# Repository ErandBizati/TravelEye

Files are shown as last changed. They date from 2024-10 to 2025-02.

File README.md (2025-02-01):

# TravelEye
<p align="center">
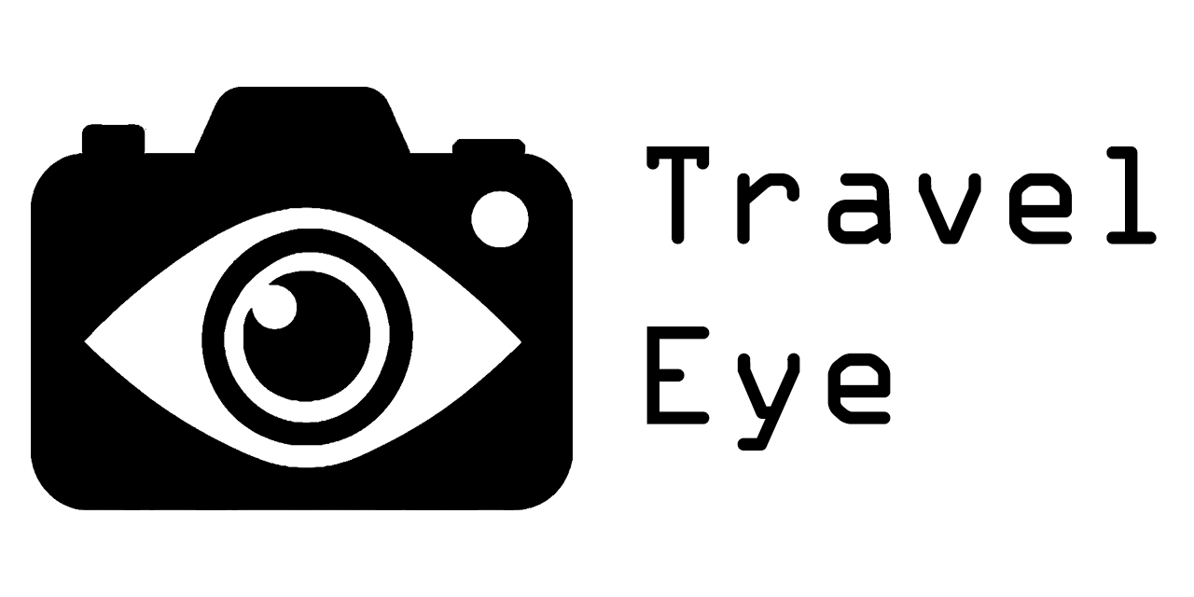
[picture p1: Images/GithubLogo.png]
  
</p>

<p align="center">
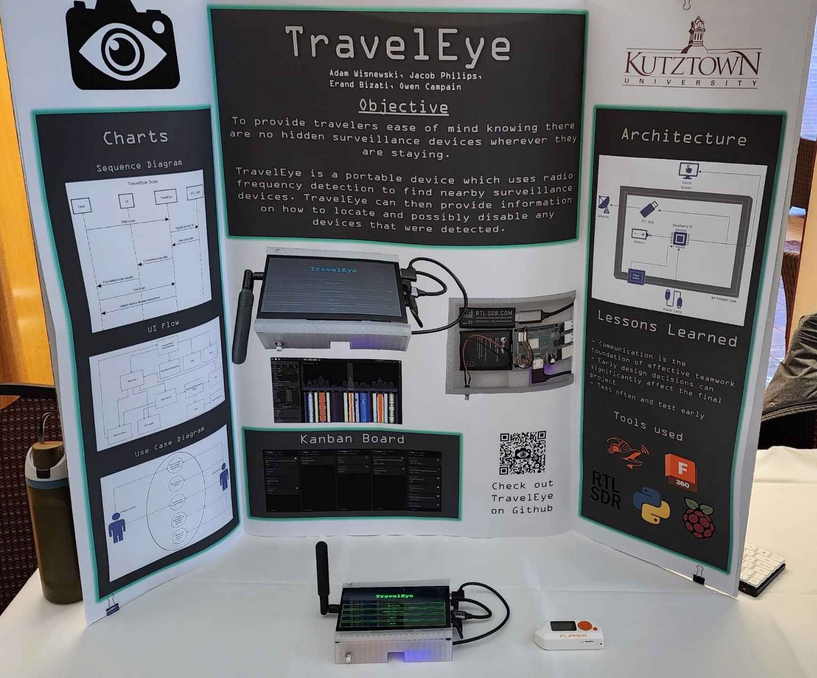
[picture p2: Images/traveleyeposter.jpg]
TravelEye Poster
  
</p>

## About
TravelEye is a portable device which used radio frequency detection to find hidden surveillance devices.
This device is aimed towards travelers with any level of technical knowledge

TravelEye scans using a list that contains frequencies that are known to be associated with surveillance devices. Any frequencies that are found to be above a determined threshold are shown to the user as possible surveillance devices.
The user can then select one of the found signals and TravelEye will then perform a focused scan on just that frequency. It will continuously scan, updating the signal strength so the user can walk around and watch the strength of the signal change for different parts of a room.
The user can then go through a few questions and TravelEye can provide advice on how to locate and possibly disable the device.

*Created by Owen Campain, Adam Wisnewski, Jacob Philips, Erand Bizati*

This project was created for a capstone course (CSC355) at Kutztown University and was formally presented at Kutztown's Demo Day 2024

## Installation
### Materials
This device was made with one specific list of components; however, this project could be recreated with slightly different components and still function. Below are the generic components required for the project along with exact models used by the team in parenthesis.
- RTL-SDR (V3)
- Raspberry Pi (3B+)
- Raspberry Pi Battery (PiSugar S Plus)
- Touch Screen (Hosyond 7-inch HDMI)
- SMA Antenna (Bingfu BFN00419)
- Normal Open Button (Twidec Push Button 7mm) 

This project uses a custom 3D printed case. The STL file for printing can be found in the repository `TravelEyeCase.stl`. Black PLA filament was used for the final case. Case design is based on the exact parts used therefore, if any components are swapped out, the case might no longer fit all components

### Assembly
The following diagram shows the layout of all the device components within the case

<p align="center">
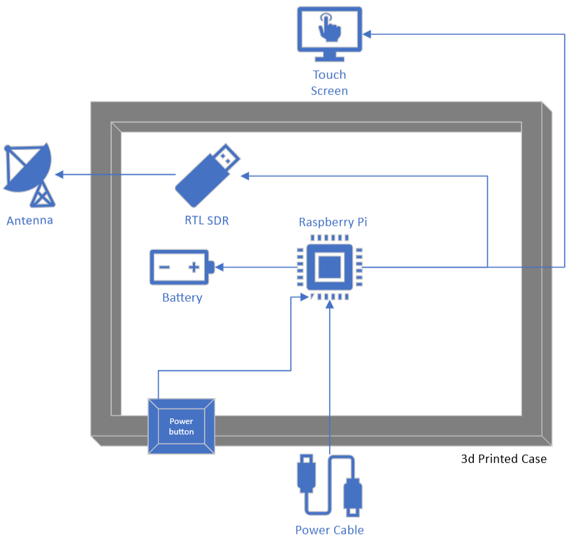
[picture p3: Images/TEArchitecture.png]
  
</p>

The screen is connected to the Raspberry Pi via HDMI. The screen is also powered by the Raspberry Pi by connecting a USB type A port of the Raspberry Pi to one of the micro-USB ports on the screen

The RTL SDR is connected to the Raspberry Pi via USB Type A. USB Type A male to female cable was used in order for the RTL-SDR to fit inside of the case, however the RTL-SDR could be connected directly.

The antenna is attached to the RTL-SDR using the SMA connector.

The power button uses the number 5 and 6 pin on the Raspberry Pi

### Software Requirements
The TravelEye program runs off the Raspberry Pi which should be running Raspbian OS. Before being able to run program though, there are a few dependencies that need to be installed first

- [RTL SDR Drivers](https://www.rtl-sdr.com/rtl-sdr-quick-start-guide/)
- [PyQt5](https://pypi.org/project/PyQt5/)
- [pi-power-button](https://github.com/Howchoo/pi-power-button.git)

### Running TravelEye
One the device has been assembled and all software requirements have been installed, TravelEye is ready to run

First make sure that `TravelEye.py`, `multipleChoiceMenu.py`, `MultiSigDetection.py` are located in the same folder before running

You can then start the program by running `TravelEye.py`

## Making Scan Adjustments
Scanning for such a wide range of different frequencies can be a challenge

There are many small adjustments to how this device scans which can affect what devices are found

There are two things that can be easily changed which can affect how the device works in different scenarios. You can adjust these values to make the device better suit your environment

### **Search list**

  This is the list of all frequencies which TravelEye will scan for.
  This list is contained in `dangerousFrequencies.txt`.

  You can add or remove any frequencies on this list. Keep in mind that all values are in MHz. The effective frequency range this device can scan for is 24 – 1766 MHz
 
  *Caution: The length of the list affects the length of scans. Adding too many frequencies can slow down the scan time*.

### Threshold
  This value represents the strength of the signal for it to be considered found. TravelEye collects data for all signals that were on the search list, however it only shows signals that we found to be above the threshold. 
  This value can be changed to make TravelEye more or less sensitive for finding signals 

  This value is contained in `MultiSigDetection.py` using the `THRESHOLD` variable. The threshold is measured in decibels

  *Caution: The UI and threshold was adjusted to only show the most prominent signals in order to not overwhelm the user with too many signals which might not be relevant. Making the threshold too low may cause all signals to be displayed which could break the UI* 

## User Guide
Here are some basic instructions and information on using TravelEye

### Instructions:

**1. Tap Start to scan**

  Scans once for all device ranges
  
  Signal strength is measured in decibels
  
  The higher the value, the stronger the signal
  
**2. Tap a found frequency to begin a focused scan**

  The device will repeatedly scan for one signal
  
  Watch the signal strength change as you move around
  
  Use this to locate where the signal is strongest
  
**3. Tap next to answer some questions to help locate the device**

### FAQ

_How close to a device do you need to detect it?_

There is no exact range on how far TravelEye can detect, it mainly depends on the strength of the signal it is trying to detect.
Most hidden devices put out a strong enough signal that TravelEye can detect as long as you are in the same room.
There have been some cases where TravelEye can detect from another room, but that is not always consistent.

_Can TravelEye find any camera or microphone?_

No, Currently TravelEye is intended to find cameras and microphones made for surveillance purposes which use radio frequency to communicate. 
Cameras and microphones which use wired or Wi-Fi communication cannot be found.
Our team would love to expand TravelEye's capabilities in the future, but for now TravelEye focuses on a more niche group of devices.

_What should I do if I find a device and cannot disable it?_

It is recommended to research surveillance and recording laws for your state/country as well as contacting the manager of the location you are staying. 
Every situation is different, so it is important to find out your rights. In many places, the authorities can be contacted if your right to privacy is being violated.

### Demo
Here is quick demo of the TravelEye device
https://www.youtube.com/watch?v=QhOCgh7br6o

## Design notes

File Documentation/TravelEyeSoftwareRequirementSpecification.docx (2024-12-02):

Software Requirement Specification

TravelEye

Dec 2, 2024

Version 2

Logo

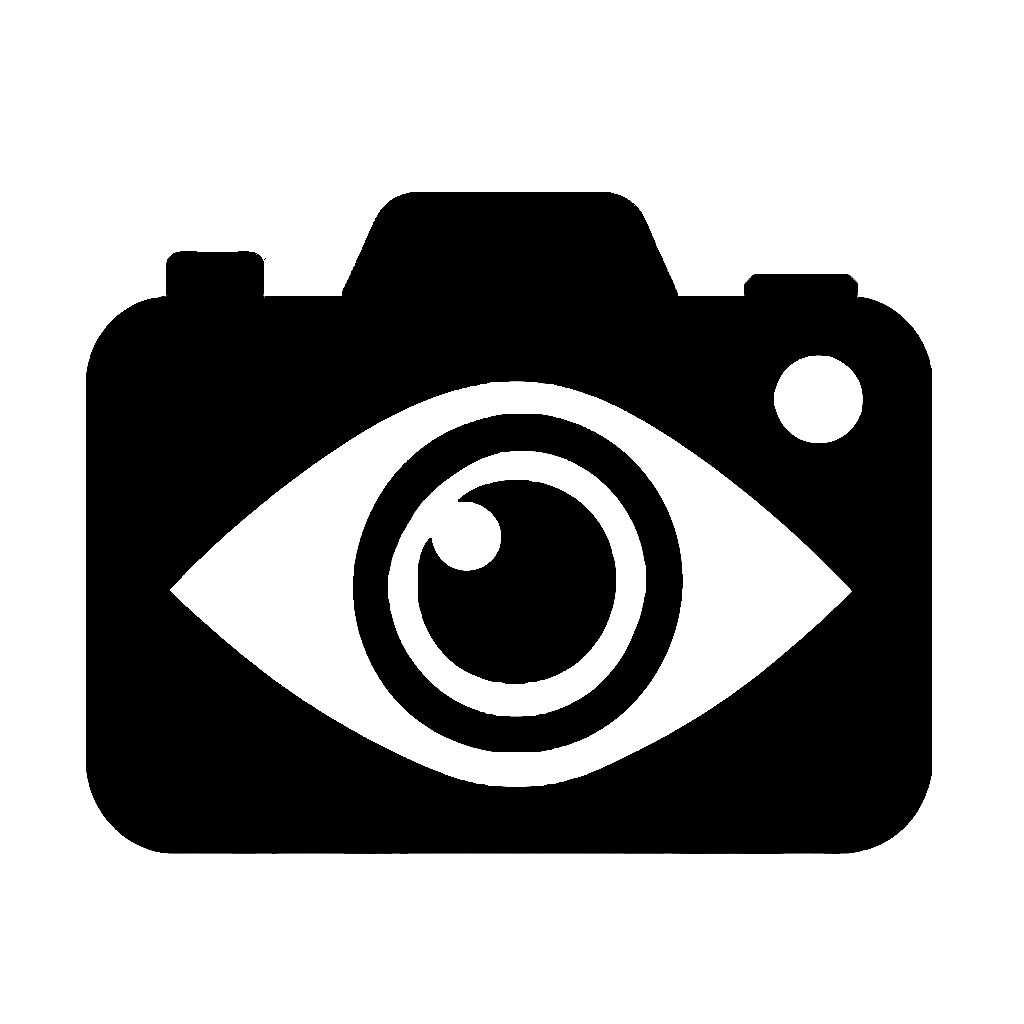
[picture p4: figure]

Presented To:

CSC354

Submitted By:

Erand Bizati

Owen Campain

Jacob Philips

Adam Wisnewski

Table of Contents

Revision History 1

1.0 Introduction 2

1.2 Scope 2

2.0 Related Documents 3

3.0 Requirements 3

3.0.1 Punch List 4

3.1 Traveler Use Cases 4

3.1.1 Disable Device Instructions 4

3.1.2 View Detected Signals 5

3.1.3 Detect Wireless Signals 5

3.1.4 Charge & Power On Device 6

3.1.5 View Help Page 6

3.1.6 User Interface Requirements 7

4.0 Non Functional Requirements 8

4.1 Other Systems 8

4.2 Usability 8

4.3 Performance 8

4.4 Maintainability 8

5.0 Architecture 9

Signature Page 9

### Revision History

Date | Author | Distributed to | Version | Description
Mar 26, 2017 | DeMarco | class | 0 | template
Feb 6, 2024 | Team | | 1 | Document creation
Dec 2, 2024 | Adam, Owen | | 2 | Revise based on final project

# 1.0 Introduction

This project aims to create a device that can help detect hidden surveillance items for travelers staying in temporary lodging (hotels, Airbnb, resorts, ect.). This device should be easy to use and accessible to all levels of technical knowledge. The device will use radio frequency detection to identify any possible hidden surveillance devices (cameras, audio recorders, gps trackers). If a potential device were to be found, instructions on how to find and disable the device will be given to the traveler.

This document outlines the different specifications and requirements for this device in order to reach the project's goal.

# 1.2 Scope

The following context diagram defines the actors that are outside the system:

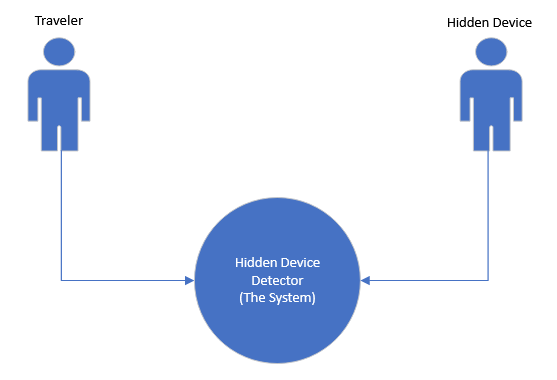
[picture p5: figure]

Traveler:

The traveler is a term used for the person using the hidden device detector.

Hidden Device:

The hidden device is any type of surveillance device which is hidden from the traveler and gives off a radio frequency which the hidden detector could capture.

The following use case diagram outline all of the possible interactions of outside actors with the system:

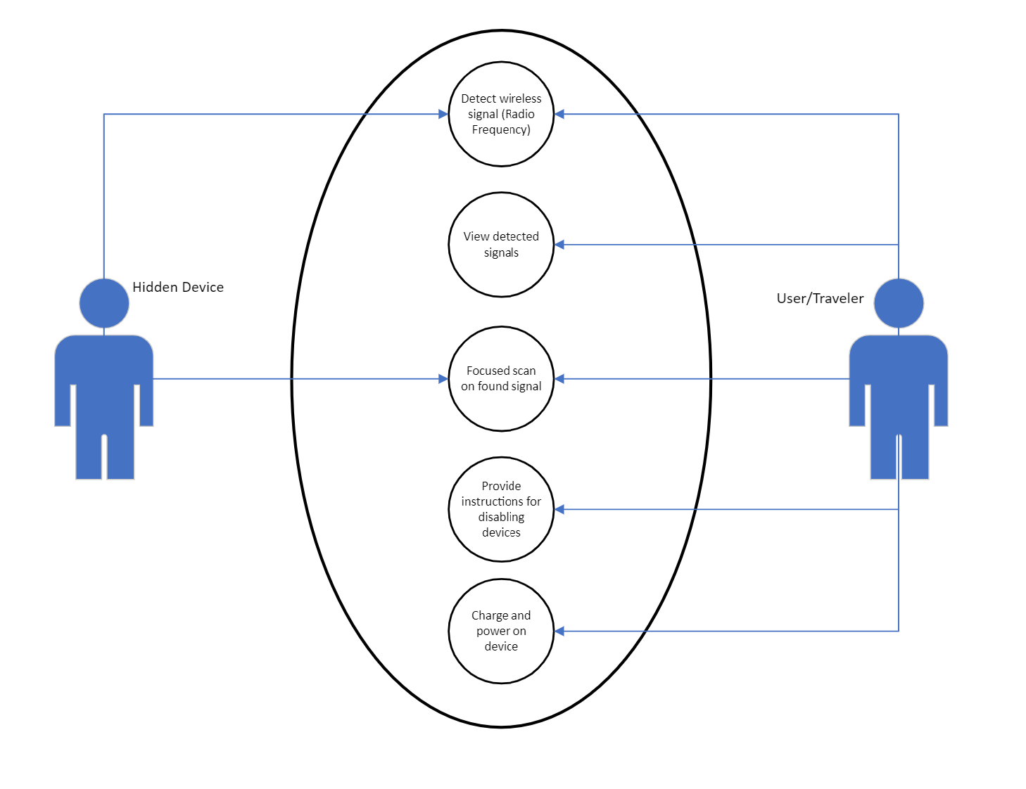
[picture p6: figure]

# 2.0 Related Documents

Context diagram link (https://livekutztown-my.sharepoint.com/:u:/g/personal/ocamp731_live_kutztown_edu/EfgFj-SR3vRDpL-uXIwYaXIBtWyubmAtK4f2kyQ_DjDRew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)

User stories link (https://livekutztown-my.sharepoint.com/:w:/g/personal/ocamp731_live_kutztown_edu/EWKVq6K5wFBMgKUtSu_duCwBPiiVJmcgEb2n8JfCiHcrRQ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)

Use case diagram link (https://livekutztown-my.sharepoint.com/:u:/g/personal/ocamp731_live_kutztown_edu/EYCpy4jRvH9Dqu8j2hU3GG8BV4mq3jjaOgJnNMZ3DxsZhQ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)

Use case description link (https://livekutztown-my.sharepoint.com/:w:/g/personal/ocamp731_live_kutztown_edu/Ef0b5joFGqxItQ4MdqtdzXMBfyyNTd9R-CmtZxJ7pXRLpg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)

# 3.0 Requirements

For each Actor, list all the user stories:

As a Traveler I want to…..

- Turn on the device
- Charge device
- Scan for signals using device
- See any signals detected
- Learn steps to disable device
- Find out how to hinder device if unable to disable

As a Hidden device I want to…..

- Emit a radio frequency for the device to read

## 3.0.1 Punch List

The following list are the items still to be resolved:

1. Figure out how to get signal information from SDR++ to our own software
2. Design the hardware architecture
3. Figure out language and platform for our software
4. Design UI flow
5. Order needed hardware

# 3.1 Traveler Use Cases

## 3.1.1 Disable Device Instructions

Description: Be informed on how to disable a hidden device when found

1. Participating Actor(s):
  a. Traveler
  b. Hidden Device
2. Entry: Hidden Device is found
3. Exit: Device is disabled
4. Flow of events:
  a. Device signal is detected
  b. User receives instructions on how to find the device
  c. User finds device
  d. User receives instructions on how to identify the type of device
  e. Hidden device type is determined
  f. User receives instructions on how to disable that type of device
  g. User disables device
5. Special Requirements:
  a. User cannot find device -> give instructions what to do next
  b. User cannot determine device type -> give instructions that could apply to all device types
  c. User cannot disable device -> give instructions on what to do next

## 3.1.2 View Detected Signals

Description: View any signals that have been detected

6. Name: View Detected Signals
7. Participating Actor(s):
  a. Traveler
  b. Hidden device
8. Entry: The user has initiated a scan, and the system must be powered on.
9. Exit: User has viewed all detected systems
10. Flow of events:
  a. User activated scan
  b. Detected signals are compiled/analyzed by the system
  c. System categorizes based on signal type, strength, and source
  d. List of detected signals is displayed on screen
  e. User reviews list of signals
11. Special Requirements:
  a. If no signals are detected, inform the user
  b. Provide a refresh button/adjust sensitivity detection

## 3.1.3 Detect Wireless Signals

Description: Detect any wireless signals (radio frequencies) present in a room

12. Participating Actor(s):
  a. Traveler
  b. Hidden Device
13. Entry: Device powered on, Scan initiated by user
14. Exit: Signal is found and the whole room is scanned
15. Flow of events:
  a. System starts scanning for signals
  b. User moves scanning device around the room
  c. Wireless signal is received
  d. Signal frequency and type are determined
  e. Signal information is stored locally
  f. Signal information (type, strength, and source) is displayed to user
16. Special Requirements:
  a. No signal found -> inform user that no signals were detected

## 3.1.4 Charge & Power On Device

Description: Charge the device fully and power it on with no problems

17. Name: Charge and Power On Device
18. Participating Actor(s):
  a. Traveler
19. Entry: A place with adequate electricity outlets
20. Exit: The hidden camera device is fully charged and powered on
21. Flow of events:
  a. Plug charger into device
  b. Screen displays battery percentage
  c. Fully charged
  d. Unplug device
  e. Press power button
22. Special Requirements:
  a. If Powered on with low battery inform user that device needs to be charged

## 3.1.5 View Help Page

Description: view a help page on how to use device

23. Participating Actor(s):
  a. Traveler
24. Entry: Start up device
25. Exit: Help page is open and read
26. Flow of events:
  a. Turn on device
  b. Wait for main menu to show
  c. Click on help button
  d. Read through Help section
27. Special Requirements:
  a. If User already knows how to use device, no need to read

## 3.1.6 User Interface Requirements

The user interface should be as simple as possible and intuitive. Since this device is a tool there should not be a long process required to get into scanning the room. Ideally the traveler should be able to turn the device on and start scanning within seconds. This can be accomplished with a clear user interface that shows each of the devices features clearly and allows for quick access to each of these features.

### 4.0 Non Functional Requirements

Below is a list of non-functional requirements gathered so far. Must be measurable.

## 4.1 Other Systems

The system should not need an internet connection or any other wireless connection to any other outside systems. It should be able to function on its own. The system does rely on SDR++ (https://github.com/AlexandreRouma/SDRPlusPlus), which is an open source project for interpreting incoming radio frequency signals.

## 4.2 Usability

The system is targeted towards any type of traveler so it must be convenient to bring along and easy to use and therefore should meet some usability requirements:

- Easily portable, comfortably fits in a standard backpack
- Usable with any level of technical knowledge (adult)
- Find majority of consumer grade surveillance devices

## 4.3 Performance

Each listening device is different and can cause differences in how they are detected, however there is an average performance expectation for most devices:

- Detect a device from 3ft away
- 90% detection rate
- 8 hr battery life

## 4.4 Maintainability

- No updates required for the software created by our team
- Since RTL-SDR and Raspian OS are outside of the project control there may be updates to these components, however the current build is stable and should be sufficient for the use in this project.

# 5.0 Architecture


Hardware Use Cases/Functionality

Raspberry Pi: Acts as the “core controller”. Processes input from detector(s).

RTL - SDR : Used to analyze RF (radio frequencies) as many hidden devices transmit data over RF.

Battery: Provides power to device without the need to be plugged in

3d Printed Case: A 3d printed case that will house all of the various components.

Antenna - Provide raw analog signal data to RTL-SDR

Touch Screen - Allows user to see scan results and interact with device

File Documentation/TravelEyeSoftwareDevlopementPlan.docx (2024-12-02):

# TravelEye

# Software Development Plan

2nd December 2024

Version 3


Submitted By:

Adam Wisnewski, Jacob Philips, Erand Bizati, Owen Campain

# REVISION HISTORY

Date | Author | Distributed to | Version | Description
Spring 24 | Prof DeMarco | teams | 0 | Update for SDP 2nd
3/22/2024 | Team | Nobody | 1 | Working on 1-4
4/1/2024 | Team | Nobody | 2 | Working on 5-11
12/2/2024 | Adam | Nobody | 3 | Edits before Final

REVISION HISTORY 1

1. PRODUCT DESCRIPTION 3

2. TEAM DESCRIPTION 3

3. SOFTWARE PROCESS MODEL DESCRIPTION 3

4. PRODUCT DEFINITION 3

Context Diagram with User Stories 3

5. PROJECT ORGANIZATION 3

5.1 Matrix of Responsibilities 3

5.2 PERT / Gantt Chart 3

6. BUDGET 4

6.1 One Page Business Plan 4

7. VALIDATION PLAN 4

Test Strategy 4

8. FEASIBILITY STUDY 4

Risk Identification 4

Risk Prioritization 4

Risk Mitigation 4

9. CONFIGURATION AND VERSION CONTROL 4

10. TOOLS 4

11. ARCHITECTURE 5

# 1. PRODUCT DESCRIPTION

Surveillance devices have become cheaper, easier to use, and more accessible for most people. As a result of this, the concern of nonconsensual surveillance has grown for the general public. This concern is especially relevant for travelers who are staying in hotels, AirBnB, and other short-term housing where there is the possibility of hidden devices being present without their knowledge. Most travelers would appreciate the peace of mind knowing there are no hidden surveillance devices in the room they are staying. Unfortunately, many methods and tools for finding surveillance devices are not easy to use and are not practical for travelers without technical knowledge.

Our product is intended to give travelers the insurance of their personal privacy without requiring technical knowledge of how to find and disable these devices. Our product uses radio frequency detection to find surveillance devices and provide easy to follow instructions on how to disable the device and how to insure their privacy. Our tool should be easy to transport and use to allow travelers to focus their travel instead of their privacy.

# 2. TEAM DESCRIPTION

## Team Skills:

| CSS/UI | Python | Raspberry pi/Sensors | 3D printing | Software Defined Radio
Owen | X | X | X | X
Adam | X | X
Jacob | X | X
Erand | X | o | X | X | o

# 3. SOFTWARE PROCESS MODEL DESCRIPTION

Describe the model to be used for this project (agile, game dev) Include justification for your choice. What are the pros and cons

The software process model which will be used for this product is the agile model. The agile model is being used because it will result in a working product with frequent collaboration to meet expectations. The agile methodology is a family of software development methodologies that prioritizes four things over four others. Specifically, it prioritizes individuals and interactions, working software, customer collaboration, and responding to change over processes and tools, comprehensive documentation, contract negotiation, and following a plan “dogmatically”.

For example, it does this by doing short releases and multiple iterations for responding to changes and collaborating with frequent changes. The methodology uses incremental design and development to update the product. User involvement is a large feature of the methodology as well to keep the customer collaborating with, while also prioritizing the individuals. Documentation is meant to be kept minimal, as it could slow down the process of creating the product. Communication is meant to be informal between members of the team.

There are many pros to the agile methodology. Specifically, it ensures that the product is consistently worked on and updated to the customer’s satisfaction. To ensure that the product is being made correctly and how the customer wants it, the team will communicate and work with the customer without making a large contract to follow exactly what it says. Not only this, but the agile methodology focuses on flexibility and collaboration for the team. With informal communication between the team, this promotes flexibility for how the team can work together. Flexibility in the product is also provided through the consistent changes throughout the creation of the product as it is constantly changing to fit what the customer wants. Collaboration is a large part of the methodology, as with minimal documentation the team must continue to collaborate to stay on the same page. Collaboration is not just with the team, but with the customer too, to keep the product exactly how they want it.

Although there are pros, there are cons as well. For the limited documentation, it can often confuse the members of the team who are not well informed, making it harder to fully complete a project. Not only this, but it is difficult to have a set deadline and set a specific time of how long the project may take. The traditional methodology, however, does not have these cons but does not have the same pros as agile does. Traditional is in many ways the opposite of agile but based on the preference of methodology and how the project should be done, you could pick the better one for the job. For this project, agile is the best methodology.

# 4. PRODUCT DEFINITION

Intended Users of the product will range from a wide variety of consumers from discerning travelers to home security specialists. The main application of the device will be most appealing to the general market of frequent flyers and people with little to no experience with RF or IR detection or networking technology or just generally apply to a less than tech savvy crowd. The other applications of the product will include security specialists or security conscious users who are slightly/significantly more experienced in terms of technology and require little to no assistance or instruction to accomplish their task.

User environments will vary from basic hotel rooms and studio apartments to upscale suites and larger style condominiums or houses. May include outdoor areas such as alleys, patios, or decks and will assist the user in looking in unconventional places if a signal is detected but no device has been found. User environments can be extended to include larger areas and environments, but the main functionality will be with smaller scale rooms and areas.

In the device aspect, the user environment will consist of all elements on a single or multiple included networks and any incoming or detected RF. Whether it be the user’s own home network, or a public or even hidden network used for listening devices. The user should have complete and total available information and should be shown all frequencies.

## Context Diagram with User Stories

Defines the scope of your system - what is inside the system and what is outside the system. High level information flow between the system and the outside users or other systems (personas)


# User:

# Turn on the device

# Scan for signals using device

# Read any signals detected

# Charge device

# Learn steps to disable device

# Hidden Device Signal:

# Emit a radio frequency for the device to read

# 5. PROJECT ORGANIZATION

## 5.1 Matrix of Responsibilities

Raspberry Pi/Sensor tasks will be worked on primarily by Owen and Erand. Owen, Adam, and Jacob will be responsible for writing programs using Python. All group members will work together in collaboration with all CSS/UI elements in the project. 3D printing the case that will house all of the components will be designed/created by Owen and Erand.

## 5.2 PERT / Gantt Chart

First cut at schedule

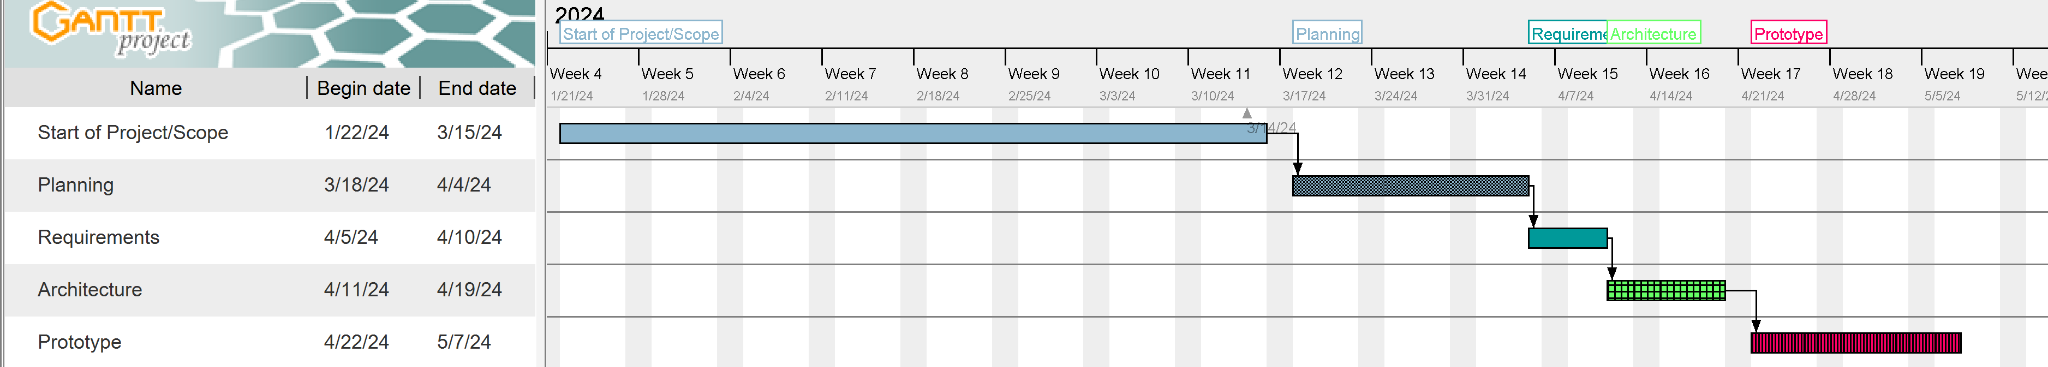
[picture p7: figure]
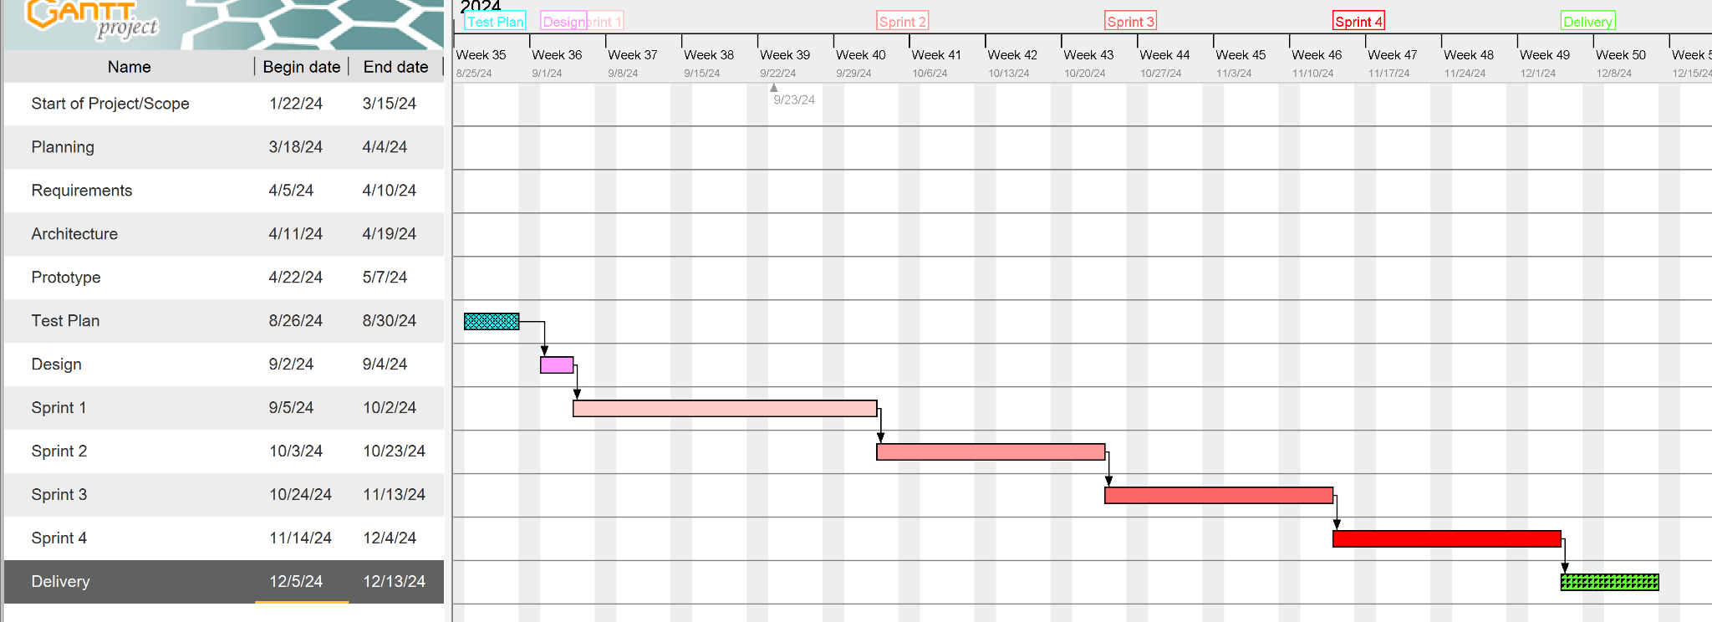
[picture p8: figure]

# 6. BUDGET

FIRST YEAR TRAVELEYE BUDGET | | | | | TOTAL
People
Team Members: | Errand | Owen | Jacob | Adam
Hourly Salary: | $55.00 | $55.00 | $55.00 | $55.00
Multiplier: | 2 | 2 | 2 | 2
Billable | $110.00 | $110.00 | $110.00 | $110.00
Hours per Week | 6 | 6 | 6 | 6
Two Semesters | $23,760.00 | $23,760.00 | $23,760.00 | $23,760.00
| | | | | -$95,040.00
Software
Name | Cost
Raspberry Pi OS | N/A
SDR++ | N/A
Github | N/A | | | | $0.00
Hardware (prototype)
Name | Cost
Raspberry Pi 3 B+ | $35.00
Screen | $35.00
RTL-SDR Dongle | $40.00
Battery | $20.00
Case | $5.00 | | | | -$135.00
Revenue
Parts cost | Manufacturing | Unit Price | Units Sold
$40.00 | $10.00 | $60.00 | 10000
| | | | | $100,000.00
| | | | NET PROFIT: | $4,825.00

# 7. VALIDATION PLAN

## Test Strategy

We will be done when we have a working product that can successfully detect hidden devices using radio waves and display that information effectively to the user. The device should have a reasonable success rate that would make the device practical in real world use.

Success would be a fully complete project with little to no bugs. The device would be able to detect cameras, display information to users, and provide tips and solutions to remove/block cameras within the area.

# 8. FEASIBILITY STUDY

## Risk Identification

Incorporating SDR++ in our program

We are using a third party application SDR++ to process the data coming from the RTL-SDR dongle. Getting the data from SDR++ might take a lot of effort and there might be more processing on our end to be done in order for the data to be useful

Radio frequency reading accuracy

We are relying on a third party dongle to read all the radio frequency data. The data from the dongle may not be accurate enough for our uses. It might require the device to be really close in order to be effective. Additionally, we need to determine which ranges of radio frequency will be flagged as a surveillance device

UI functionality

The UI of our device will require different paths and must present the data in a user friendly way. The UI may take more effort than intended and could end up having a UI that is not friendly to nontechnical people.

## Risk Prioritization

1. Radio frequency reading accuracy
2. Incorporating SDR++ in our program
3. UI functionality

## Risk Mitigation

These risk issues arise from a lack of knowledge our team has on certain aspects of this project. To limit this, starting on the prototype as soon as possible will allow our team time to learn these new concepts and test them well before our deadline. Ideally these problems can be figured out early on, so we can focus on other, less risky parts of the project

We will first prototype the UI and start gathering data from the dongle. We can split our team and focus on these two aspects and bring them together in our first prototype

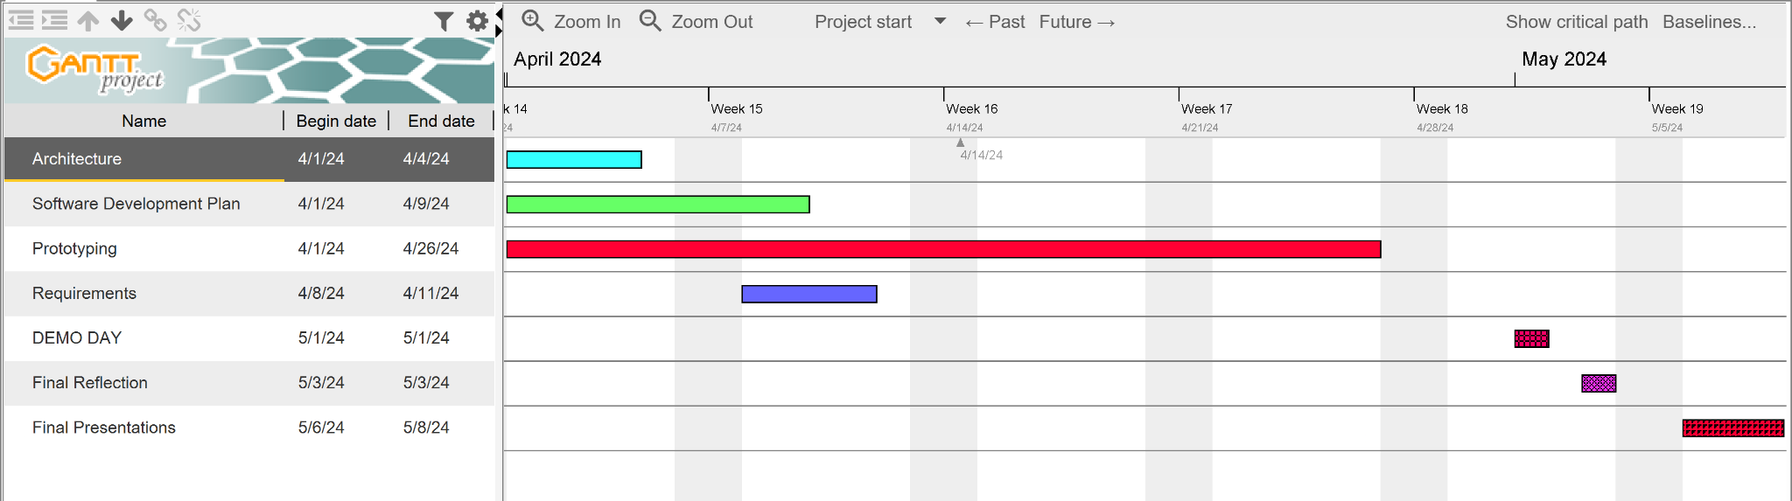
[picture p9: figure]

# 9. CONFIGURATION AND VERSION CONTROL

We will be primarily utilizing GitHub for version control and all project related artifacts. Versions of our software will be stored to GitHub and loaded onto the device for testing.

# 10. TOOLS

Github - communication and code saving/importing

RTL-SDR - physical device and drivers for detecting radio frequencies

Python - Programming language used

Raspberry Pi OS - the debian based operating system our device will run on

Flipper Zero - Used for testing frequency detection

Autodesk Fusion - CAD software for designing case

# 11. ARCHITECTURE

Components

- RTL-SDR (V3)
- Raspberry Pi (3B+)
- Raspberry Pi Battery (PiSugar S Plus)
- Touch Screen (Hosyond 7-inch HDMI)
- SMA Antenna (Bingfu BFN00419)
- Normal Open Button (Twidec Push Button 7mm)
- HDMI cable
- Micro USB cable
- Male to Female USB cable

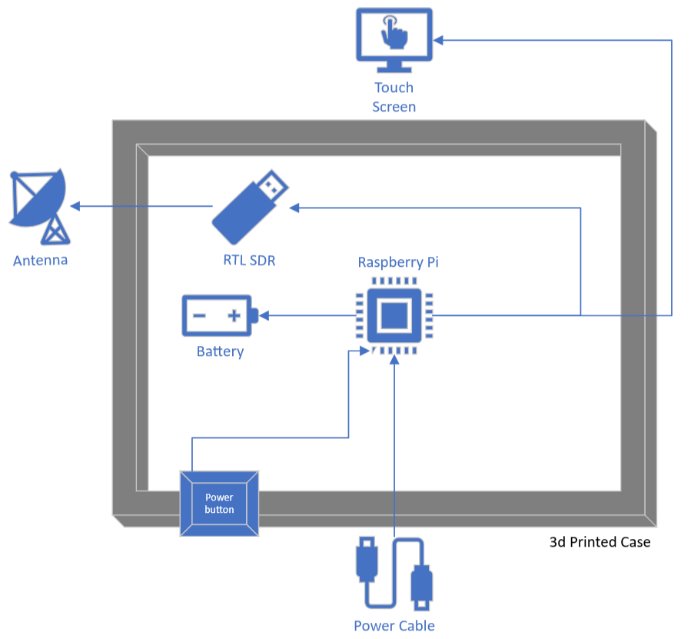
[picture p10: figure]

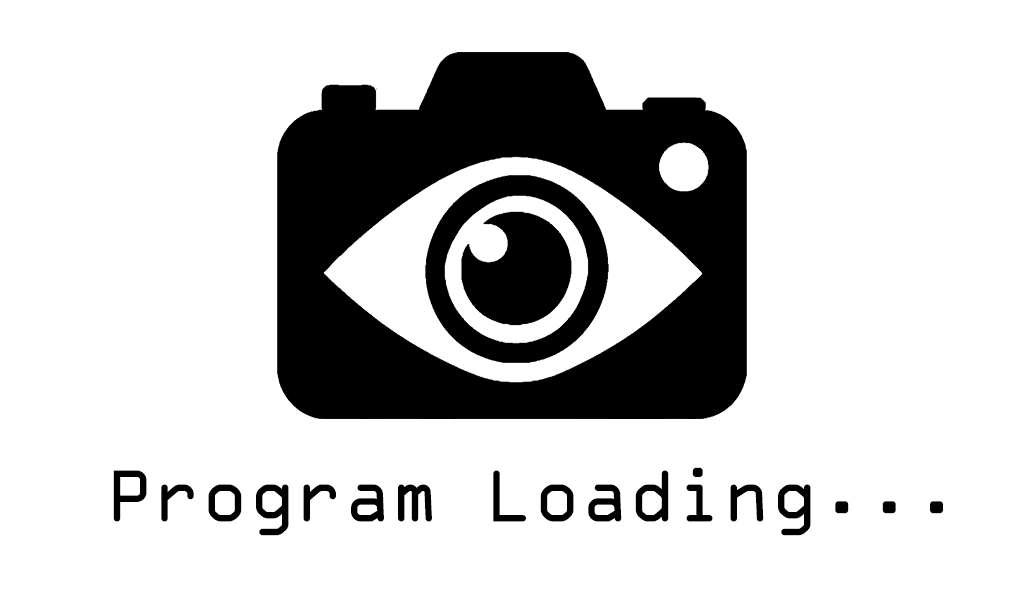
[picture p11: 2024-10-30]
Images/LoadingScreen.png

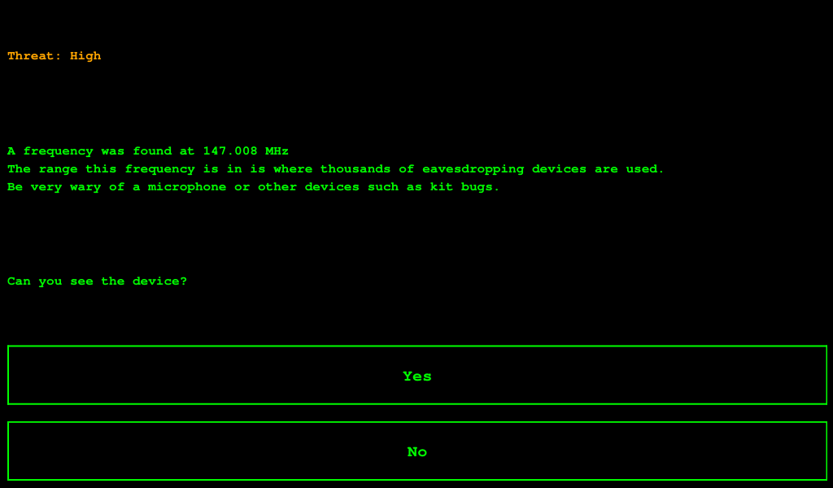
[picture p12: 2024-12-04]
Images/2024-12-04-170135_1024x600_scrot.png

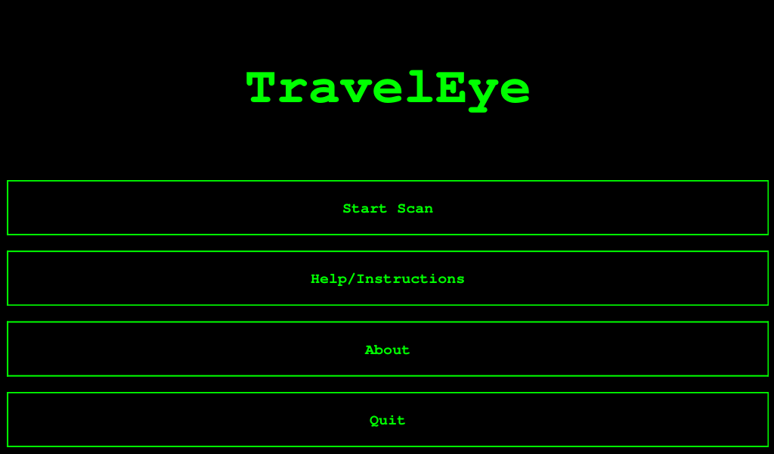
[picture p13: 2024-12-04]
Images/2024-12-04-170116_1024x600_scrot.png

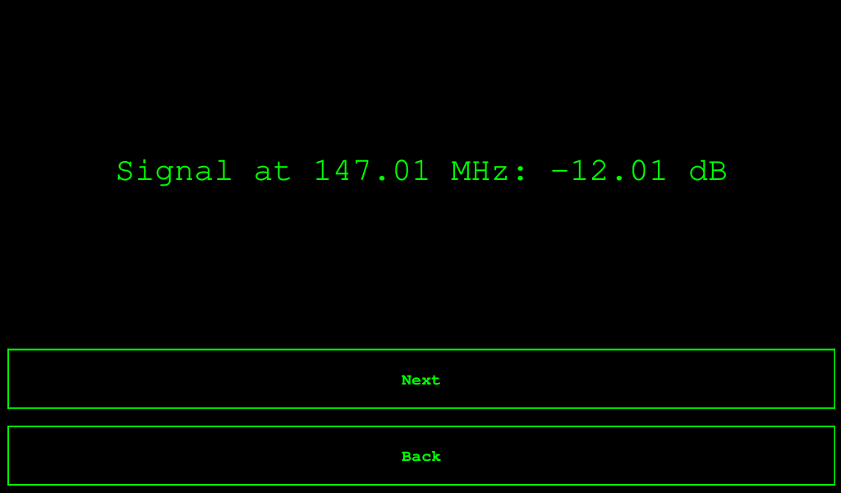
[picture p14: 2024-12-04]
Images/2024-12-04-170129_1024x600_scrot.png

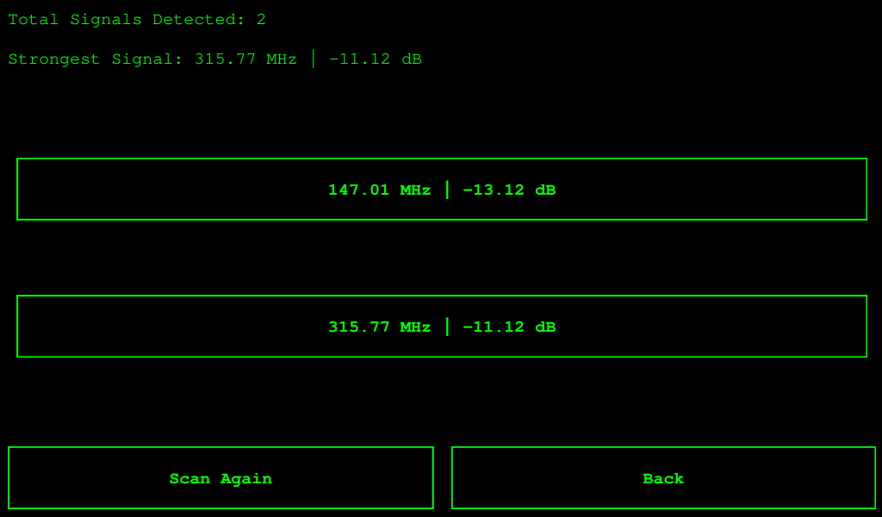
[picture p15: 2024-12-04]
Images/2024-12-04-170121_1024x600_scrot.png

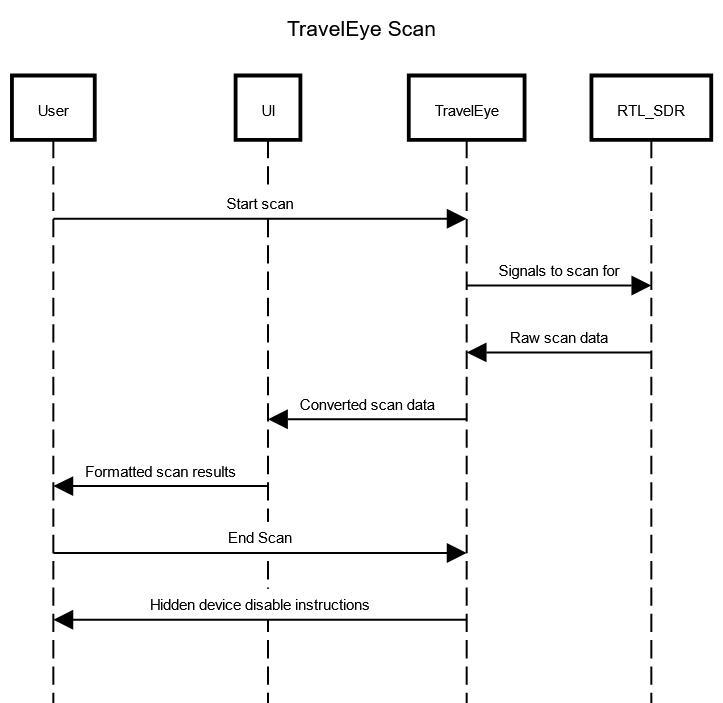
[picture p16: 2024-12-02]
Documentation/TravelEyeHighLevelSequence.png

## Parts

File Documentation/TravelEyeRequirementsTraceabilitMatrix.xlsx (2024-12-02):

Requirements Traceability Matrix: One Stop for all documents, diagrams, tests, and code
STEP 1 |  |  |  |  |  |  | STEP 2 | STEP 3 | STEP 4
SRS Section ID | Requirement name | Owner (team member name) | Requirement Source | Priority | Use Case Diagram doc link | Prototype Candidate | Test Plan Section Number | Architecture Component | Sprint (hotlink kanban board here) | Test Case (link) | Sequence Diagram (link) | Detailed Design Doc Section | Code Respository Link
3.1.1 | Disable Device Instructions | Jacob | Team | Must have | Use Case Diagram (https://github.com/owencampain/TravelEye/blob/2bf58ed4ddf7743673638c5013b27ed3c89ab827/Documentation/UseCaseDiagram.vsdx) | yes | 1 | Screen | Kanban Board (https://github.com/users/owencampain/projects/1/views/1) | Test Case 1 (https://docs.google.com/document/d/1C9UTQntVNpYPsejGFwxFmKmY-k9o_IpPrcNLgrlLiSs/edit?usp=drive_link) | Sequence Diagram (https://discordapp.com/channels/1195015860612505731/1202993695213752391/1207749603730923530) | 3.1.1 | Github (https://github.com/owencampain/TravelEye/blob/main/runTests.py)
3.1.2 | View Detected Signals | Owen | Team | Must have |  | no | 2 | SDR++, Antenna |  | Test Case 2 (https://docs.google.com/document/d/1bPMI64PM3Hat8vIvzpA8hYWrq5Q4yCDk5xKIz3sZhRY/edit?usp=drive_link) |  | 3.1.2
3.1.3 | Detect Wireless Signals | Owen | Team | Must have |  | yes | 3 | SDR++, Antenna |  | Test Case 3 (https://docs.google.com/document/d/1eJOb83Vnof6BlTqo3B6s_h3hXEOIt9Ytg5a7tXEsHl8/edit?usp=drive_link) |  | 3.1.3
3.1.4 | Charge & Power On Device | Erand | Team | Nice to have |  | no | 4 | Battery |  | Test Case 4 (https://docs.google.com/document/d/1IQIRT2JYYG-h-NNLfHBYZEKQik9DmBK4L4Y806FX8RM/edit?usp=drive_link) |  | 3.1.4
3.1.5 | View Help Page | Erand | Team | Nice to have |  | no | 5 | Device |  | Test Case 5 (https://docs.google.com/document/d/16yBUGB_RG-V2P0gY7ZAlWndviFdBELcWrNSB1uNEK14/edit?usp=drive_link) |  | 3.1.5
3.1.6 | User Interface Requirements | Adam | Team | Must have |  | yes | 6 | Device |  |  |  | 3.1.6
3.1.7 | Multiple Choice Menu | Adam | Team | Must have |  | yes |  | PiQt5, device, screen |  |  |  | 3.1.7

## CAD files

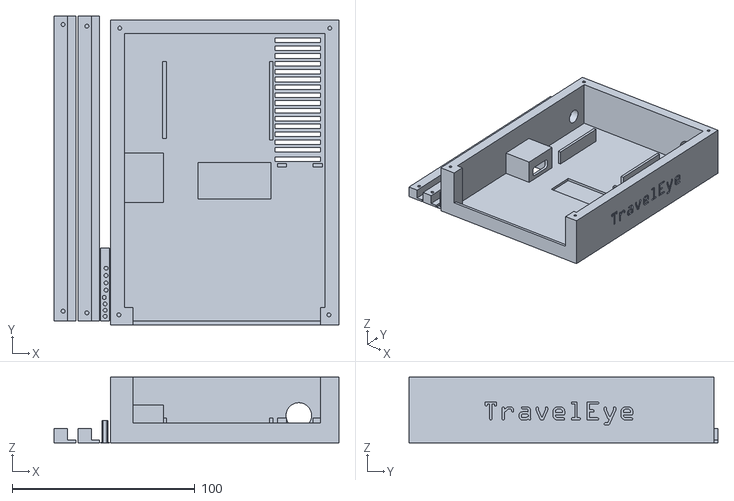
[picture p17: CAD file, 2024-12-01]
TravelEyeCase.stl
156.0 x 169.0 x 36.0

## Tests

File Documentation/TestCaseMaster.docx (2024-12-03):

Project Name: TravelEye | Sprint Number: 5

Test Case
Sprint Deliverable Name: | Test Date: leave blank for test plan
Test Title (What are we testing): Disable Device Instructions | Test executed by: leave blank for test plan
SRS Corresponding (hotlink to SRS section) Section 3.1.1 | Test Environment:

Description: Once a signal is found, the user will go through steps on how to disable the hidden device. As the user goes through the steps, they will answer questions which will then give them instructions based on their scenario.

Pre-condition(What do we assume): A hidden device signal was found

Dependencies: (What do we need): A hidden device exists and is able to be found

Step | Test steps | Test Data | Expected Result | Actual Result | Status(Pass/ Fail) | Notes
1. 1 | Check initial device found screen | Detectable signal | Any found signals displayed with button to get instruction to disable device
2. 11 | Click disable device instructions button | | Prompted with two buttons, is the device visible or not
3. | Click device is visible | | Given instructions on how to identify and disable device
4. | Click device is not visible | | Given instructions on how to find device, then option for device was not found or found
4.1. | Click device was found | | Given instructions on how to disable device
4.2. | Click device was not found | | give instructions on how to protect from any hidden devices
5 | Quit back to menu at every during each step above | | Send user back to main menu

Project Name: TravelEye | Sprint Number: 3

Test Case
Sprint Deliverable Name: | Test Date:
Test Title (What are we testing): View Detected Signals | Test executed by:
SRS Corresponding (hotlink to SRS section) Section 3.1.2 | Test Environment:

Description: Once a signal from a hidden device is found, the device should display all the signals found and if their type could be determined

Pre-condition(What do we assume): a scan was started and a signal was found

Dependencies: (What do we need):

Step | Test steps | Test Data | Expected Result | Actual Result | Status(Pass/ Fail) | Notes
| View Camera Signal | camera giving off signal | signal shown with camera type
| View Microphone Signal | microphone giving off signal | signal shown with camera type
3. | View unknown signal | signal without type attached | show signal with type unknown
4. | Select continue scan | detected signal | Starts scanning, after scan done, any results from previous scans stay
5.
6.

Project Name: TravelEye | Sprint Number: 3

Test Case
Sprint Deliverable Name: | Test Date:
Test Title (What are we testing): Detect wireless signal | Test executed by:
SRS Corresponding (hotlink to SRS section) Section 3.1.3 | Test Environment:

Description: Scan various different signals to ensure that the scan will pick them up. The signal type should be displayed if it could be determined, otherwise should show up as unknown. If no signal is present there should be no signals detected

Pre-condition(What do we assume): Scan was started

Dependencies: (What do we need): Radio signal receiver working

Step | Test steps | Test Data | Expected Result | Actual Result | Status(Pass/ Fail) | Notes
| Scan for signal from Flipper Zero | set frequency sent from Flipper Zero | Signal is found
| Scan for signal from camera/microphone | camera which emits a frequency | Signal is found
3. | Scan when no signal is present | N/A | No signal found
4. | Scan when signal is in another room | | Signal found
5.
6.

Project Name: TravelEye | Sprint Number: best guess

Test Case
Sprint Deliverable Name: best guess for now | Test Date: leave blank for test plan
Test Title (What are we testing):Charge and Power on | Test executed by: leave blank for test plan
SRS Corresponding (hotlink to SRS section) Section 3.1.4 | Test Environment:

Description: Receive power and input from both a power source and someone pressing the power button. The device should display power level in a percentage, and an active charging indicator, as well as a boot sequence once fully booted up.

Pre-condition(What do we assume): Device was plugged in

Dependencies: (What do we need): Power and Input

Step | Test steps | Test Data | Expected Result | Actual Result | Status(Pass/ Fail) | Notes
| Receive power to unit | Device is charging | power is being received | leave blank for plan | leave blank for plan
| Start Boot Sequence | Sequence starts | Device begins booting
3. | Boot Device and Display Power | Device successfully boots and starts | Device is operational
4.
5.
6. | (add more steps as needed)

Project Name: TravelEye | Sprint Number: best guess

Test Case
Sprint Deliverable Name: best guess for now | Test Date: leave blank for test plan
Test Title (What are we testing): | Test executed by: leave blank for test plan
SRS Corresponding (hotlink to SRS section) Section 3.1.5 | Test Environment:

Description: Once a signal from a hidden device is found, or a hidden device connected network is found, the device should display devices found and if their type could be determined

Pre-condition(What do we assume): The device connected to a network and was found accordingly

Dependencies: (What do we need):

Step | Test steps | Test Data | Expected Result | Actual Result | Status(Pass/ Fail) | Notes
| View connected devices | View all connected devices to a network | All devices on a network are expected to show | leave blank for plan | leave blank for plan
| View Unknown or Hidden devices | View all unknown or suspicious hidden devices on a network | All hidden devices on a network are expected to show
3. | Continue Scan | Continue appropriately | The scan will continue as normal
4.
5.
6. | (add more steps as needed)

Project Name: TravelEye | Sprint Number: best guess

Test Case
Sprint Deliverable Name: best guess for now | Test Date: leave blank for test plan
Test Title (What are we testing): Shine Flashlight at Camera Lenses | Test executed by: leave blank for test plan
SRS Corresponding (hotlink to SRS section) Section 3.1.6 | Test Environment:

Description: Device should shine a light and illuminate all invisible camera lenses

Pre-condition(What do we assume): There are camera lenses that the user wishes to see

Dependencies: (What do we need):

Step | Test steps | Test Data | Expected Result | Actual Result | Status(Pass/ Fail) | Notes
| Prompt User to scan for hidden physical lights | Camera Lens | User will be informed about searching for physical hidden cameras | leave blank for plan | leave blank for plan
| User will tap on icon for flashlight | | Flashlight icon or prompt will come on screen to inform
3. | Flashlight will illuminate and device will instruct | | Flashlight will be used to scan the room for any hidden cameras
4.
5.
6. | (add more steps as needed)
